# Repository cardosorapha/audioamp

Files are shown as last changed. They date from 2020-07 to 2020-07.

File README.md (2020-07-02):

# Amplificador de Audio

Essa é uma placa contendo um filtro passa-baixas de terceira ordem de Chebyshev com um amplificador de áudio baseado no TDA2030. No [esquemático](./Esquemático.pdf), as conexões estão descritas e separadas em blocos, que fizeram parte do projeto da [PCB](./PCB.pdf). Para montar o projeto, uma lista de materiais interativa está disponível [aqui](https://cardosorapha.github.io/audioamp/).

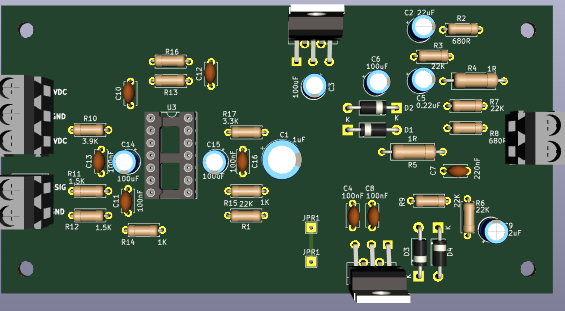
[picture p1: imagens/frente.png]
Frente


## Uso

Esse circuito recebe um sinal como entrada, dá um ganho o filtra com as seguintes especificações

* fs1 = 1200Hz
* fp1 = 4200hz
* Amin = 40dB
* Amax = 2dB
* Gcc = 0.5V/V

O sinal filtrado segue para o amplificador que suporta cargas de até 8R. 

### Alimentação

* +14V indicado por +VDC
* -14V indicado por -VDC
* GND

### Entradas

* Sinal de áudio indicado por por +SIG
* GND

### Saídas

* OUT1
* OUT2

Devem ser conectados ao speaker.

### Fabricação

Os arquivos gerber estão disponíveis na pasta [gerber](./gerber) para fabricação. 

## Customização

Pré-requisitos:
* [KiCAD](https://kicad-pcb.org/)

O projeto pode ser facilmente clonado com:
```
git clone https://github.com/cardosorapha/audioamp.git
```

Qualquer filtro passa-baixas de terceira ordem de topologia Sallen-Key pode ser implementado sem nenhuma modificação na placa, apenas nos componentes. Com isso, é possível modificar seus parâmetros facilmente, adaptando-os para a aplicação.

## Contato

Raphael Cardoso - cardosodeoliveir@gmail.com

Link do Projeto: [https://github.com/cardosorapha/audioamp](https://github.com/cardosorapha/audioamp)

# Desenvolvido na 

<p align="center">
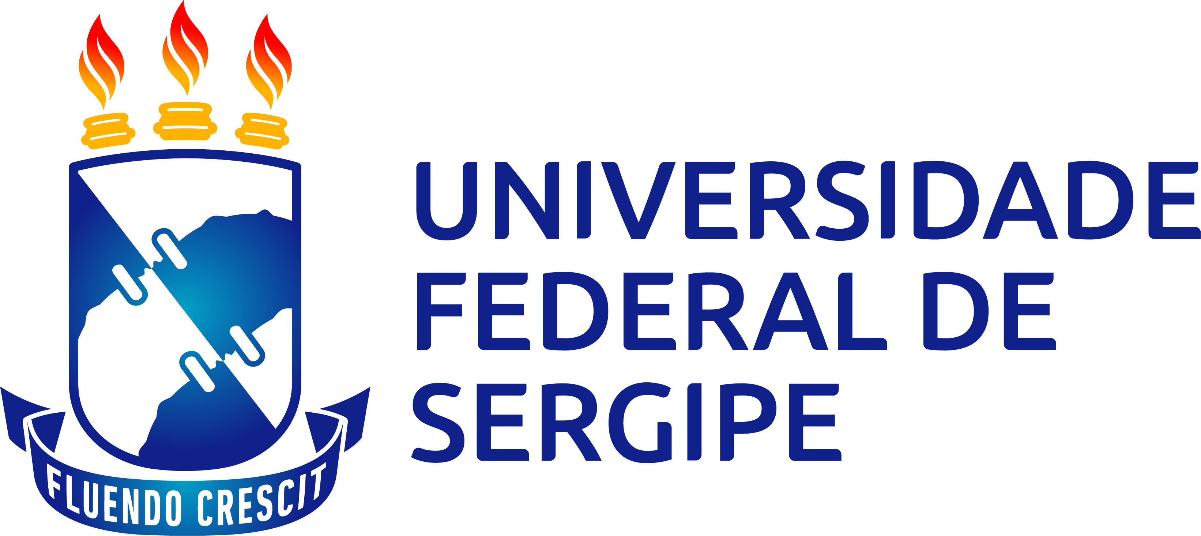
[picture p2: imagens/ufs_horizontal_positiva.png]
  
</p>

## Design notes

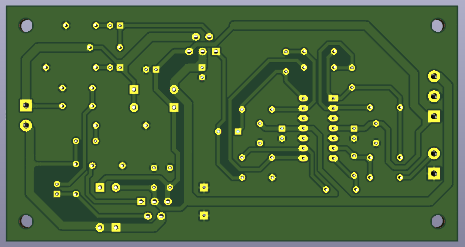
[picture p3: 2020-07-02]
imagens/tras.png

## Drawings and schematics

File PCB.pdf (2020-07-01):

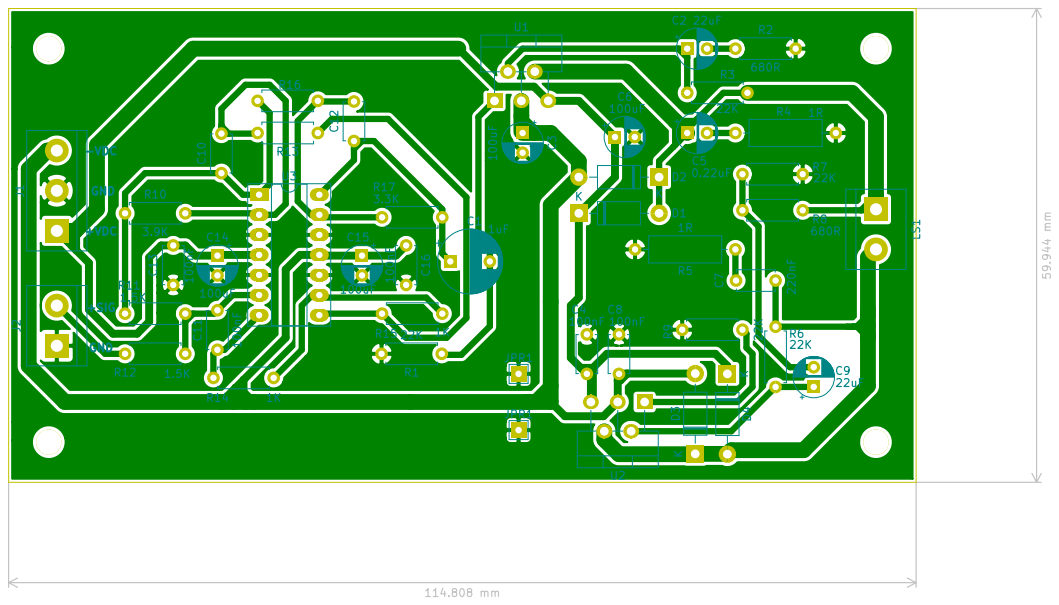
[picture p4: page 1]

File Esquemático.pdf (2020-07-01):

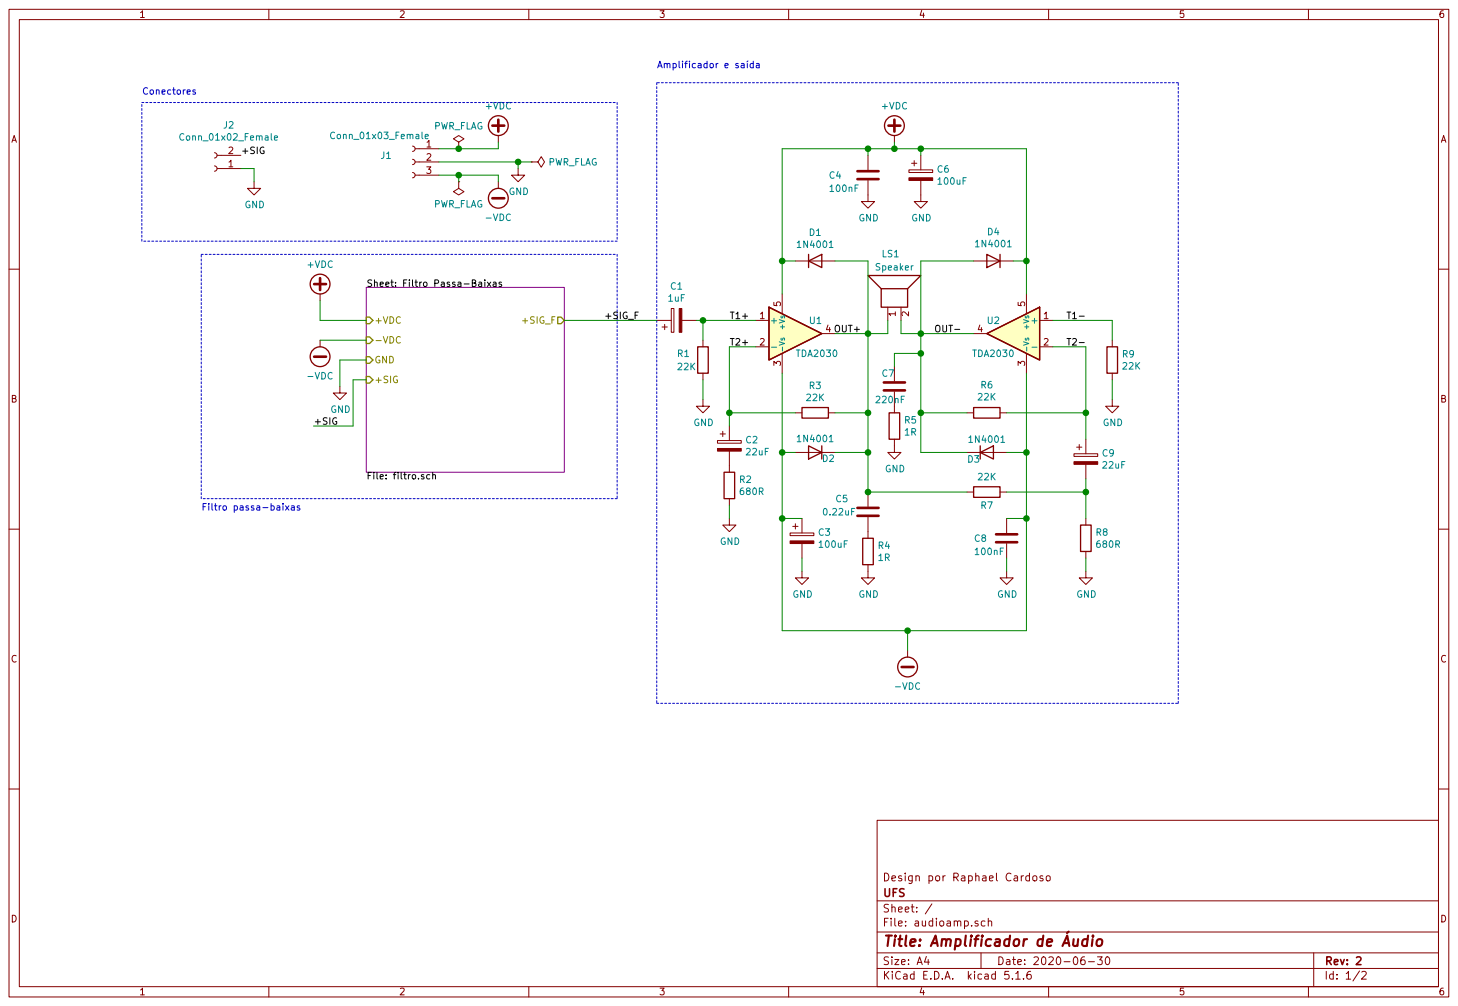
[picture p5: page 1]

Sheet: Filtro Passa-Baixas File: filtro.sch +VDC

File: audioamp.sch Sheet: / UFS Design por Raphael Cardoso

Id: 1/2 Title: Amplificador de Áudio

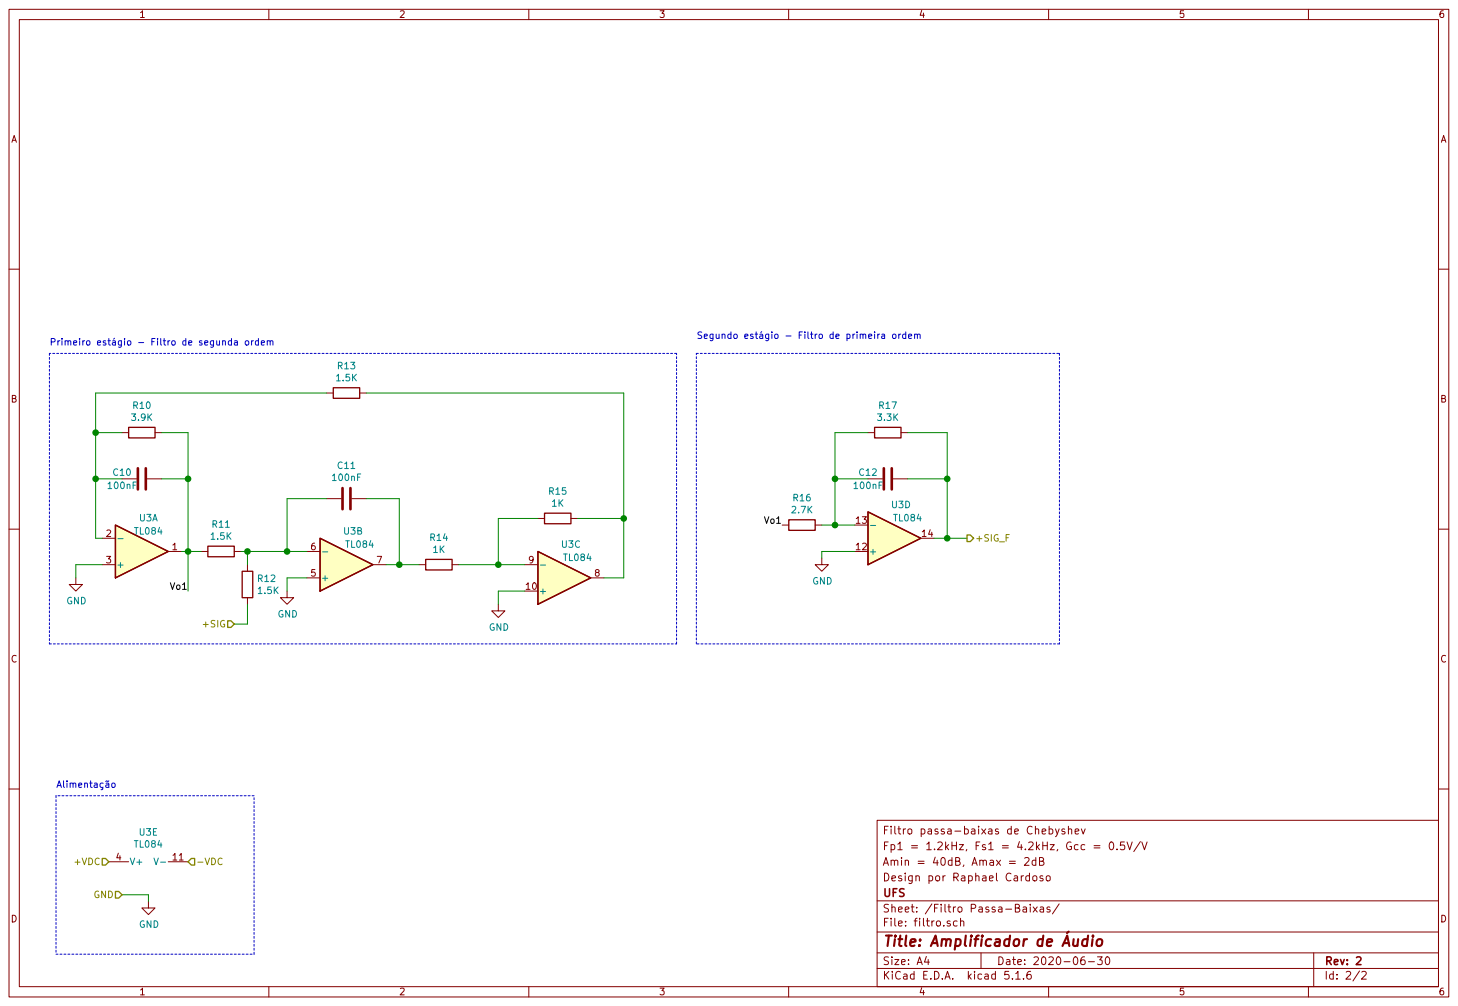
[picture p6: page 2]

Filtro passa-baixas de Chebyshev C10

Fp1 = 1.2kHz, Fs1 = 4.2kHz, Gcc = 0.5V/V
Amin = 40dB, Amax = 2dB
File: filtro.sch Sheet: /Filtro Passa-Baixas/ UFS Design por Raphael Cardoso

Id: 2/2 Title: Amplificador de Áudio

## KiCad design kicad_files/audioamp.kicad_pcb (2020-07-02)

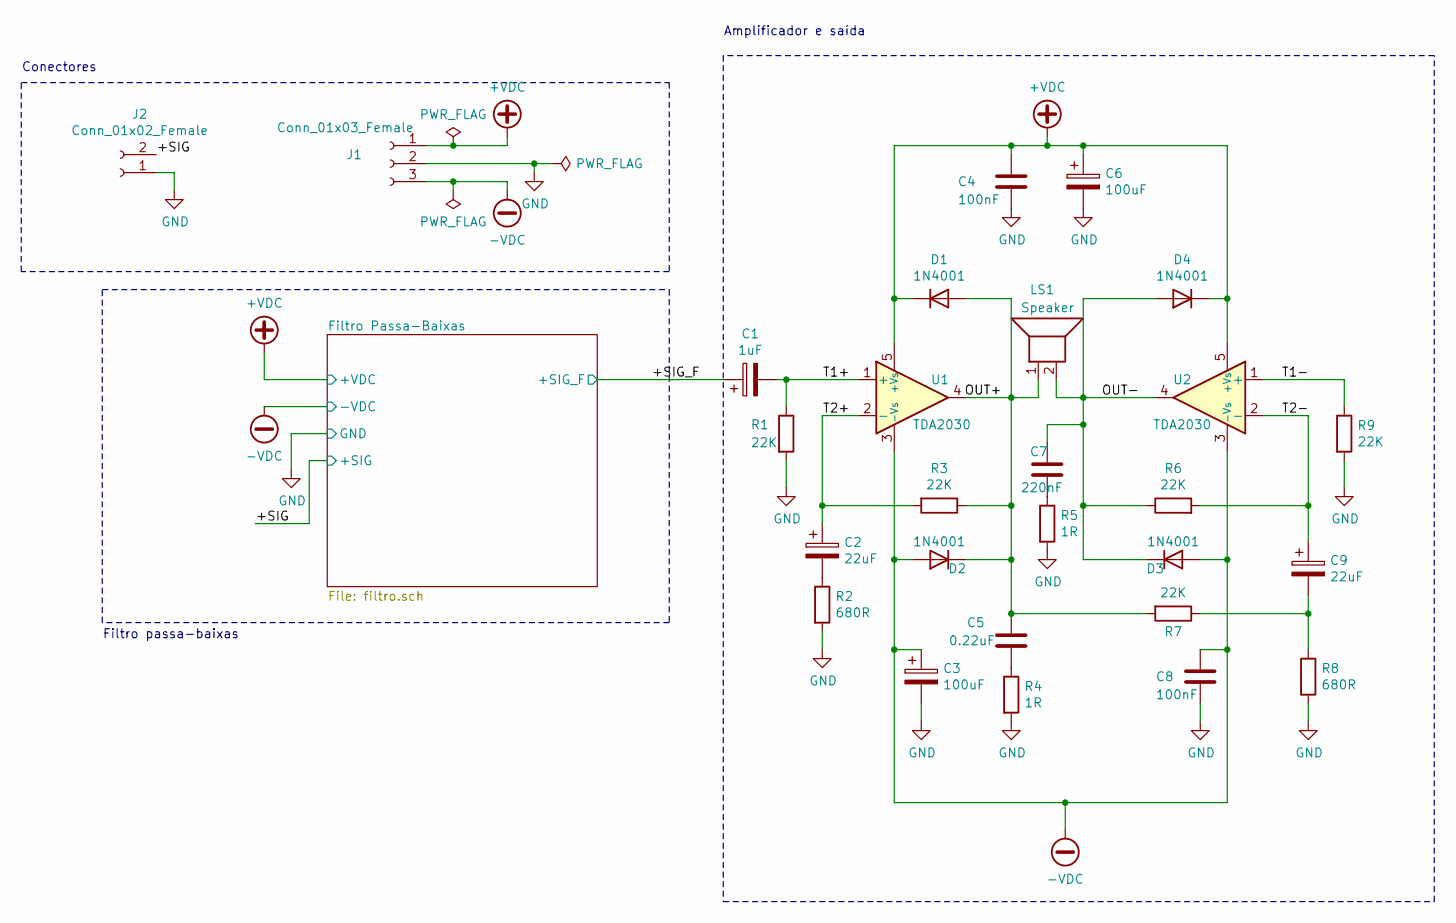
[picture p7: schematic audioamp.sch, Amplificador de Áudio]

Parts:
C1: 1uF; CP_Radial_D5.0mm_P2.50mm
C2, C9: 22uF; CP_Radial_D5.0mm_P2.50mm
C3, C6: 100uF; CP_Radial_D5.0mm_P2.50mm
C4, C8: 100nF; C_Disc_D4.7mm_W2.5mm_P5.00mm
C5: 0.22uF; CP_Radial_D5.0mm_P2.50mm
C7: 220nF; C_Disc_D4.7mm_W2.5mm_P5.00mm
D1, D2, D3, D4: 1N4001; D_DO-41_SOD81_P10.16mm_Horizontal
J1: Conn_01x03_Female; TerminalBlock_bornier-3_P5.08mm
J2: Conn_01x02_Female; TerminalBlock_bornier-2_P5.08mm
LS1: Speaker; TerminalBlock_bornier-2_P5.08mm
R1, R3, R6, R7, R9: 22K; R_Axial_DIN0207_L6.3mm_D2.5mm_P7.62mm_Horizontal
R2, R8: 680R; R_Axial_DIN0207_L6.3mm_D2.5mm_P7.62mm_Horizontal
R4: 1R; R_Axial_DIN0414_L11.9mm_D4.5mm_P15.24mm_Horizontal
R5: 1R; R_Axial_DIN0309_L9.0mm_D3.2mm_P12.70mm_Horizontal
U1, U2: TDA2030; TO-220-5_P3.4x3.7mm_StaggerOdd_Lead3.8mm_Vertical

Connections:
+VDC: C4.1, C6.1, D1.1 (K), D4.1 (K), J1.1, U1.5 (+Vs), U2.5 (+Vs); also elsewhere on the board
-VDC: C3.1, C8.1, D2.2 (A), D3.2 (A), J1.3, U1.3 (-Vs), U2.3 (-Vs); also elsewhere on the board
/+SIG: J2.2; also elsewhere on the board
/+SIG_F: C1.1; also elsewhere on the board
/OUT+: C5.1, D1.2 (A), D2.1 (K), LS1.1, R3.1, R7.2, U1.4
/OUT-: C7.1, D3.1 (K), D4.2 (A), LS1.2, R6.1, U2.4
/T1+: C1.2, R1.1, U1.1 (+)
/T1-: R9.1, U2.1 (+)
/T2+: C2.1, R3.2, U1.2 (-)
/T2-: C9.1, R6.2, U2.2 (-)
GND: C3.2, C4.2, C6.2, C8.2, J1.2, J2.1, R1.2, R2.2, R4.2, R5.2, R8.2, R9.2; also elsewhere on the board
unnamed: C2.2, R2.1
unnamed: C5.2, R4.1
unnamed: C7.2, R5.1
unnamed: C9.2, R7.1, R8.1

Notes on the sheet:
Conectores
Filtro passa-baixas
Amplificador e saída

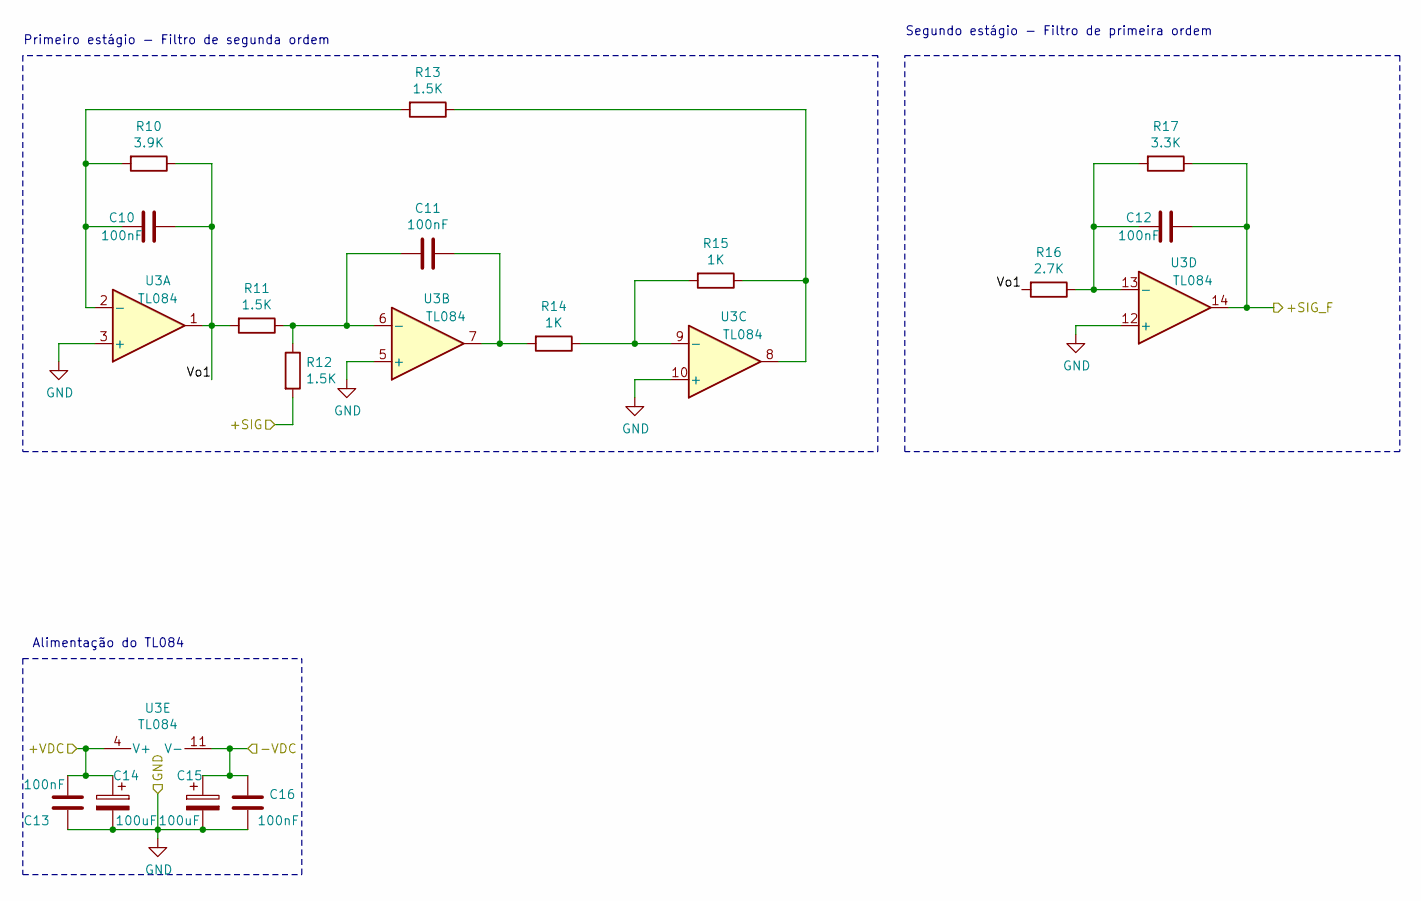
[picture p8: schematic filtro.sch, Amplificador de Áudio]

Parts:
C10, C11, C12, C13, C16: 100nF; C_Disc_D4.7mm_W2.5mm_P5.00mm
C14, C15: 100uF; CP_Radial_D5.0mm_P2.50mm
R10: 3.9K; R_Axial_DIN0207_L6.3mm_D2.5mm_P7.62mm_Horizontal
R11, R12, R13: 1.5K; R_Axial_DIN0207_L6.3mm_D2.5mm_P7.62mm_Horizontal
R14, R15: 1K; R_Axial_DIN0207_L6.3mm_D2.5mm_P7.62mm_Horizontal
R16: 2.7K; R_Axial_DIN0207_L6.3mm_D2.5mm_P7.62mm_Horizontal
R17: 3.3K; R_Axial_DIN0207_L6.3mm_D2.5mm_P7.62mm_Horizontal
U3: TL084; DIP-14_W7.62mm_Socket_LongPads

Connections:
+VDC: C13.1, C14.1, U3.4 (V+); also elsewhere on the board
-VDC: C15.1, C16.1, U3.11 (V-); also elsewhere on the board
/+SIG: R12.2; also elsewhere on the board
/+SIG_F: C12.1, R17.1, U3.14; also elsewhere on the board
/Filtro Passa-Baixas/Vo1: C10.1, R10.1, R11.2, R16.2, U3.1
GND: C13.2, C14.2, C15.2, C16.2, U3.3 (+), U3.5 (+), U3.10 (+), U3.12 (+); also elsewhere on the board
unnamed: C10.2, R10.2, R13.2, U3.2 (-)
unnamed: C11.1, R14.2, U3.7
unnamed: C11.2, R11.1, R12.1, U3.6 (-)
unnamed: C12.2, R16.1, R17.2, U3.13 (-)
unnamed: R13.1, R15.1, U3.8
unnamed: R14.1, R15.2, U3.9 (-)

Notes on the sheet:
Primeiro estágio - Filtro de segunda ordem
Segundo estágio - Filtro de primeira ordem
Alimentação do TL084

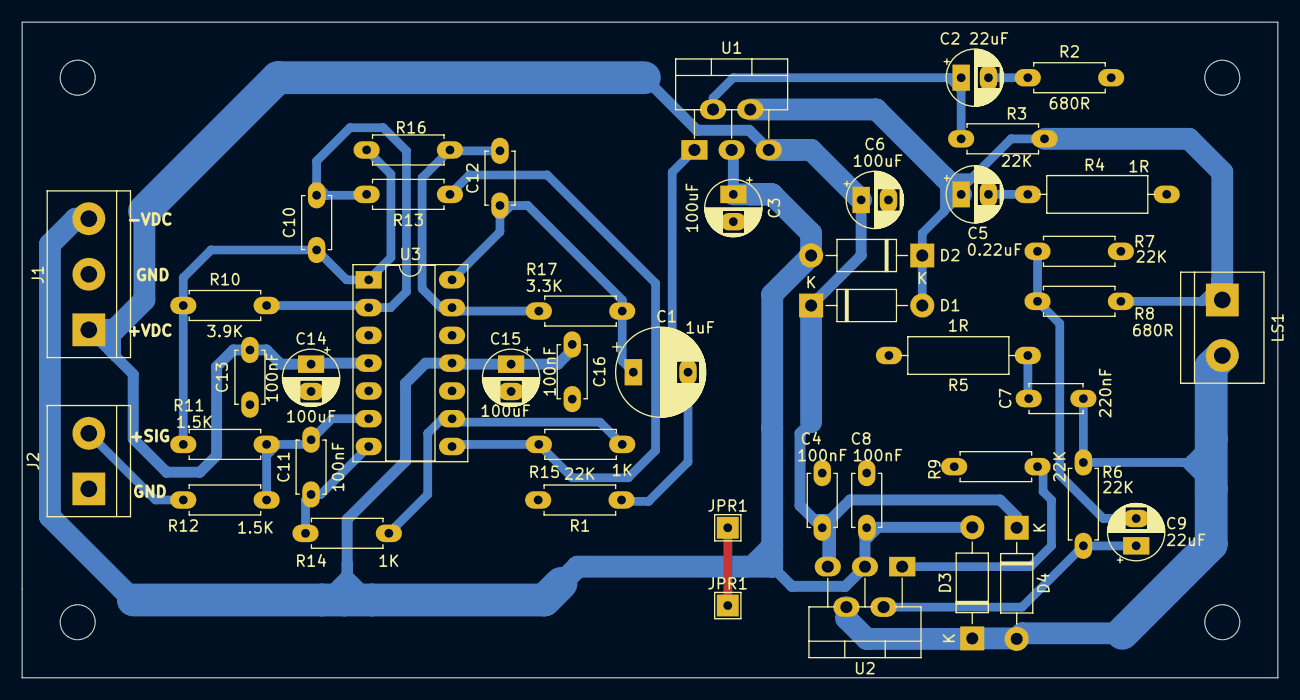
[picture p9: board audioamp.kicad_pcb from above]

Board: 2 copper layers, 114.8 x 59.9 mm, 45 parts (0 on the bottom side), 22 nets.

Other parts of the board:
JPR1, JPR1#2: TestPoint_THTPad_2.0x2.0mm_Drill1.0mm

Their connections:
GND: JPR1.1, JPR1#2.1; also elsewhere on the board

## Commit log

2020-06-30 Criação do projeto e adição do Datasheet
    [audioamp.kicad_pcb, audioamp.sch]
2020-06-30 Componentes posicionados e anotados
    [audioamp.sch]
2020-07-01 Amplificador conectado - Não verificado
    [audioamp.sch]
2020-07-01 Adicionados valores do amplificador - Verificado
    [audioamp.sch]
2020-07-01 Adicionados componentes do filtro em esquema hierárquico
    [audioamp.sch]
2020-07-01 Colocados arquivos do esquemático do filtro
    [filtro.sch]
2020-07-01 Esquemático do filtro conectado e revisado
    [filtro.sch]
2020-07-01 Adicionados comentários e PDF gerado
    [audioamp.sch, filtro.sch]
2020-07-01 Adicionados footprints aos componentes
    [audioamp.sch, filtro.sch]
2020-07-01 Importados componentes no layout PCB e adicionados capacitores de bypass no TL084
    [audioamp.kicad_pcb, filtro.sch]
2020-07-01 Roteado o filtro passa-baixas, 1 jumper usado
    [audioamp.kicad_pcb]
2020-07-01 Roteado o amplificador, 1 jumper usado no total
    [audioamp.kicad_pcb]
2020-07-01 Alguns componentes movidos para melhorar a organização, ainda um jumper usado
    [audioamp.kicad_pcb]
2020-07-01 Adicionados buracos de parafusos e gerados gerbers
    [audioamp.kicad_pcb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]
2020-07-01 Adicionado bill of materials
2020-07-01 Pequeno ajuste
    [audioamp.kicad_pcb]
2020-07-01 BOM como index.html para hosting do GITHUB
2020-07-02 Trilhas engrossadas
    [audioamp.kicad_pcb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]
2020-07-02 Pads mais grossos para facilitar solda
    [audioamp.kicad_pcb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]
